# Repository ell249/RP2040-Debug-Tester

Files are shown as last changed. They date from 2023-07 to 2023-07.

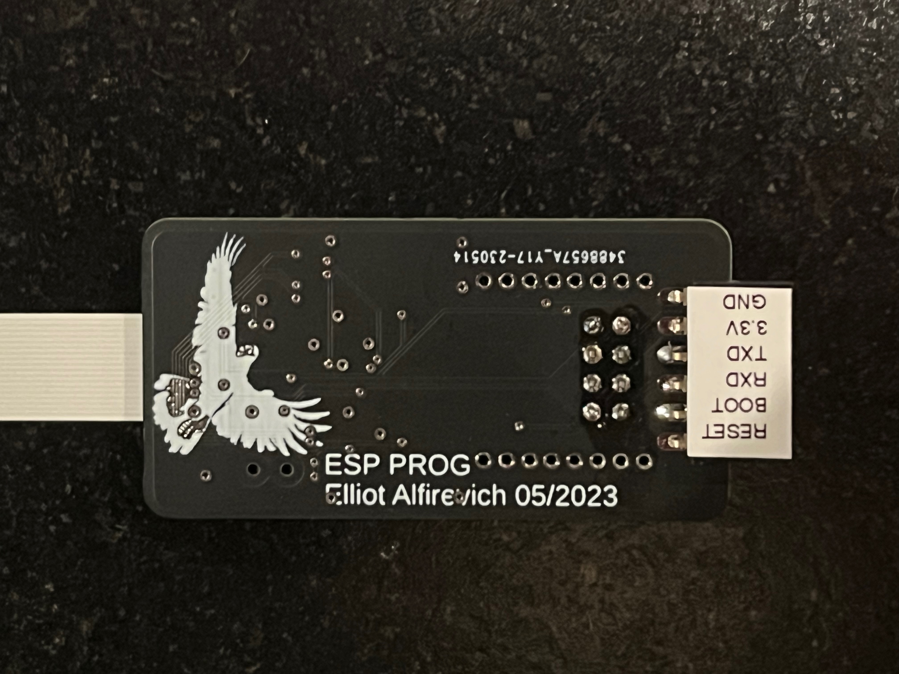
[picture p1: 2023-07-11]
Photos/IMG_8755.jpeg

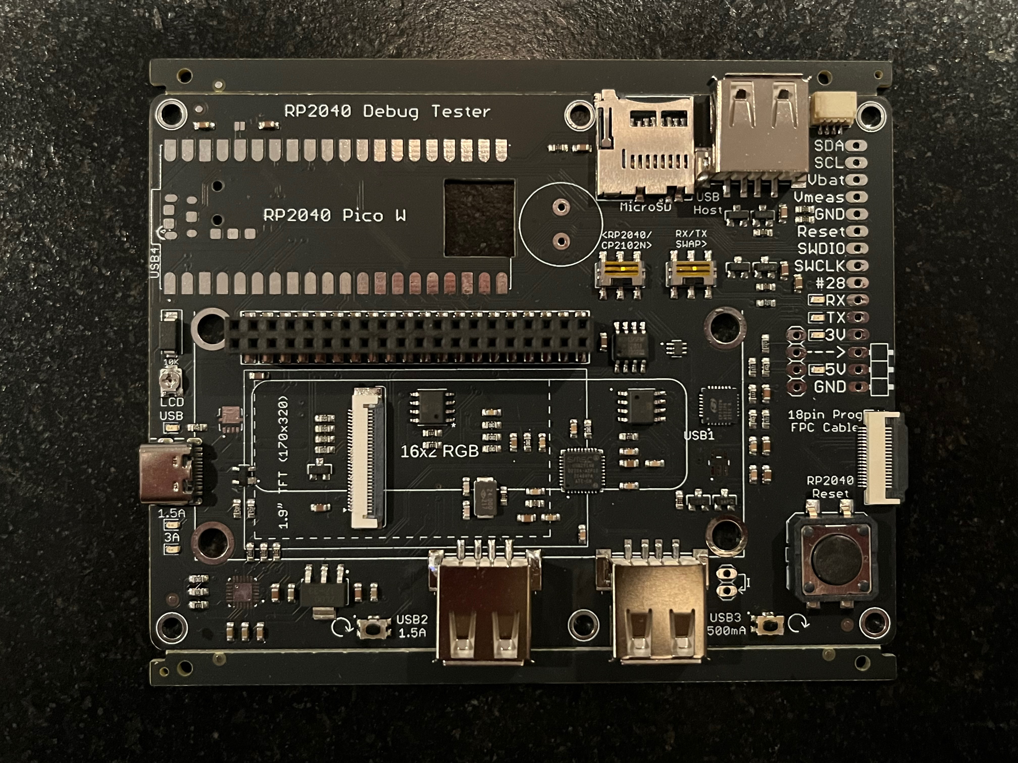
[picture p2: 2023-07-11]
Photos/IMG_8753.jpeg

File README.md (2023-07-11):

## RP2040 Debug Tester
### Licence and design:
-	RP2040 Debug Tester adapted by Elliot Alfirevich http://ell-tech.com/ 
-	Based on Adafruit RP2040 Tester Brains https://github.com/adafruit/RP2040-Based-Tester-Brains-PCB by Adafruit (ladyada & evaherrada) 
-	Licenced under Creative Commons Attribution-ShareAlike 3.0 Unported
-	4-layer impedance controlled circuit board, JLC04161H-7628 to ensure appropriate trace impedance for USB.

### Added features:
1.	USB-Serial converter CP2102N added to snoop serial UART bus, and allow direct serial programming of devices on test using the changeover DPDT switches.
2.	USB Hub with device power reset buttons and USB device current measurement at JP7 using Nordic PPK2 or similar. 
3.	Extra power supply functions added in the FPC 18-pin and external device 0.1in header as JP6.
4.	Additionally JP5 provides connection point for a Nordic PPK2 or similar for measuring load current of external prog-cable devices. “TEST” pin provides opportunity for custom voltages/measured currents. 
5.	Nordic PPK2 can be permanently mounted via the mounting holes and standoffs.

### Notes/changes to Adafruit design:
1.	Dedicated 3.3V regulator provided, in lieu of using the in-built RP2040 buck-boost converter. 
2.	Diode included on 3.3V supply to RP2040 VSYS to prevent back-feeding of ~5V onto the 3.3V bus from plugging in the RP2040 USB port.
3.	USB-C PD controller STUSB4500LQTR ensures enough VBUS current is provided by the host. Previously used 5.1k CC resistor method – but strictly compliant USB hosts would limit supply to 500mA which was not enough.
4.	RTS/DTR logic transistors added for ESP boot/reset to be generated from the CP2102N.
5.	High side switch (Option 1) or separate regulator (Option 2) required to power CP2102N because the CP2102N defaults to pull-up on USB data lines, causing the USB hub to disable the port at start-up (doh!)
6.	USB Hub USB2514B added to enable one cable to the host computer. 
   1.	Port 1 – CP2102N USB-Serial converter
   2.	Port 2 – USB port inc. 1.5A charging
   3.	Port 3 – USB port inc. 500mA power measurement via jumper JP7
   4.	Port 4 – RP2040 via test points.
7.	USB Hub controller strapped to report Port 1 as “non-removable” and enable USB charging support on Port 2.
8.	USB Hub controller requires an external crystal and 1M resistor. Check as newer QFN packages don’t require this resistor.
9.	SD card changed due to part availability. Note new part changes card detect from NO to NC which requires change in Brains library code.
10.	TFT connection not tested. Directly copied from original design.

### Original Adafruit Design
Forked from https://github.com/adafruit/RP2040-Based-Tester-Brains-PCB

This board is what we use internally at Adafruit to program and test boards with microcontrollers on them. 
   * An [RP2040 Pico](https://www.adafruit.com/product/5525) (or perhaps PicoW?) is used to run the test software
   * [Use a 16x2 LCD (ideally RGB backlight)](https://www.adafruit.com/product/398) for display output with color feedback such as green for pass, red for fail. RGB backlight is WS2811-controlled. Don't forget to set the contrast pot on first usage.
   * Serial1 hardware UART has RX/TX pin switch to flip directions
   * 1.9" TFT connector is placed but hasn't been tested or used yet
   * Piezo buzzer can be used for audible feedback alerts
   * STEMMA QT I2C port
   * Big reset button
   * Firmware files can be stored on MicroSD card which is slotted in. 
   * Connect the right hand side, either the 0.1" header or 18-pin EYESPI-like FPC connector to the device-under-test jig which can be different for each product. 
   * [USB Host testing is done with bitbang PIO support in TinyUSB](https://github.com/adafruit/Adafruit_TinyUSB_Arduino), USB 5V power can be turned on / off 
   * Use Philhower RP2040 core for programming
   * The RP2040 brains can perform ESP32 programming, RP2040-via-USB, AVR ICSP/UPDI, or SWD DAP. [See the TestBed library for some examples.](https://github.com/adafruit/Adafruit_TestBed)

### License

Originally designed by Limor Fried/Ladyada for Adafruit Industries. Adafruit invests time and resources providing this open source design, please support Adafruit and open-source hardware by purchasing products from [Adafruit](https://www.adafruit.com)!

Creative Commons Attribution/Share-Alike, all text above must be included in any redistribution. 
See license.txt for additional details.

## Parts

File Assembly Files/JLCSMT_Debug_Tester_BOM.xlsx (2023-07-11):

Comment | Designator | Footprint | JLCPCB Part#
LED_BLUE | 1.5A, 3.3V, 3A, 5V, ATTACH, RX, TX | LEDC1608X55N_FLAT-B | C72038
10uF | C1, C2, C3, C4, C5, C6, C7, C8, C12, C22, C28, C31, C35 | 0603-NO | C194427
1uF | C13, C27, C29, C32, C33, C34 | 0603-NO | C15849
4.7uF | C16, C24, C26 | 0603-NO | C329940
12pF | C18, C21 | 0603-NO | C182482
0.1uF | C9, C10, C11, C14, C15, C17, C19, C20, C23, C25, C30 | 0603-NO | C14663
STEMMA_I2C_QT | CONN1 | JST_SH4 | C160404
B140-13-F | D1 | DIOM5226X290N | C85098
SP0503BAHTG | D2 | SOT143 | C7074
WS2811-SOP8 | IC1 | SO08-SKINNYPADS | C114581
USB4105_REVA | J1 | GCT_USB4105_REVA | C963370
MEM2052-00-195-00-A_REVA | J2 | GCT_MEM2052-00-195-00-A_REVA | C266607
16x2 LCD | JP4 | 2X20_SMT_MALE | C2685092
BSS138 | Q1, Q3, Q5, Q7 | SOT23-WIDE | C2874697
DMG34x5 | Q2, Q4, Q8 | SOT23-WIDE | C96616
10K | R1, R2, R3, R4, R5, R29, R30, R35 | 0603-NO | C309083
1K | R10, R21, R25, R28, R34, R36 | 0603-NO | C103232
27 | R11, R14, R16, R18 | 0603-NO | C881414
100K | R15, R17, R19, R20, R22, R26 | 0603-NO | C103200
1M | R23 | 0603-NO | C217860
12K | R24 | 0603-NO | C217716
20K | R27 | 0603-NO | C163879
22K | R6, R7, R8, R13 | 0603-NO | C705918
47K | R9, R12, R31, R32, R33 | 0603-NO | C912116
DPDT SLIDE | SW1, SW2 | EG1390 | C223854
12mm SMT | SW3 | B3F-40XX-SMT | C2931098
DISP_LCD_ST7789_1.9IN_SS | TFT1 | TFT_1.9IN_170X320_30P_SS | C375905
UMH3NTN | U2 | SOP65P210X100-6N | C123008
CP2102N-A02-GQFN28R | U3 | IC_CP2102N-A02-GQFN28R | C964632
MIC2505-1YM-TRSOIC-8_M_MCH-L | U4 | SOIC-8_M_MCH-L | C627817
MIC2026-1YM | U5 | SOIC127P599X173-8N | C144190
USB2514B-AEZG | U6 | VQFN50P600X600X100-36N | C16251
KMR421GULCLFS | USB2_SW, USB3_SW | SW_KMR421GULCLFS | C99271
10K Trimmer | VR1 | TRIMPOT_BOURNS_TC33X-2 | C719176
NCP1117ST33T3G | VR2 | SOT230P700X170-4 | C444421
USB A | X2, X5, X6 | USB_HOST-SMT | C112455
TESTER_PROGCABLE_FLIP | X3 | FPC_0.5MM_18PIN | C181732
24MHZ 7pf | X4 | NX5032 | C295068

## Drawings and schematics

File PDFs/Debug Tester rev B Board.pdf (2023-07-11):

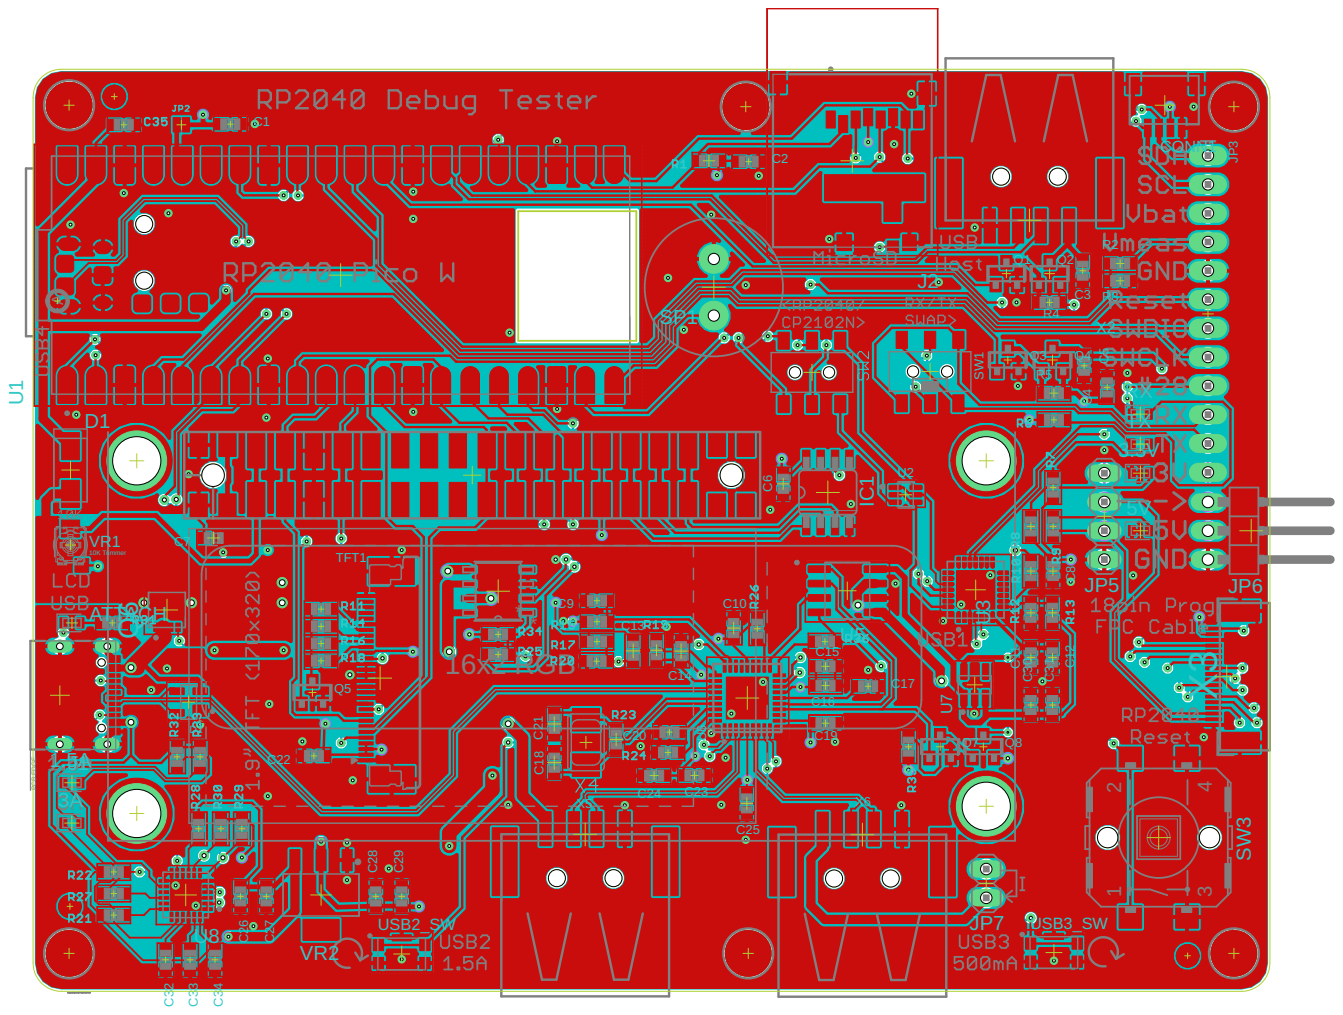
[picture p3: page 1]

X100 3202/ 60, hci verifl At oill Eyb sni ar Br et seT gube D0402PR

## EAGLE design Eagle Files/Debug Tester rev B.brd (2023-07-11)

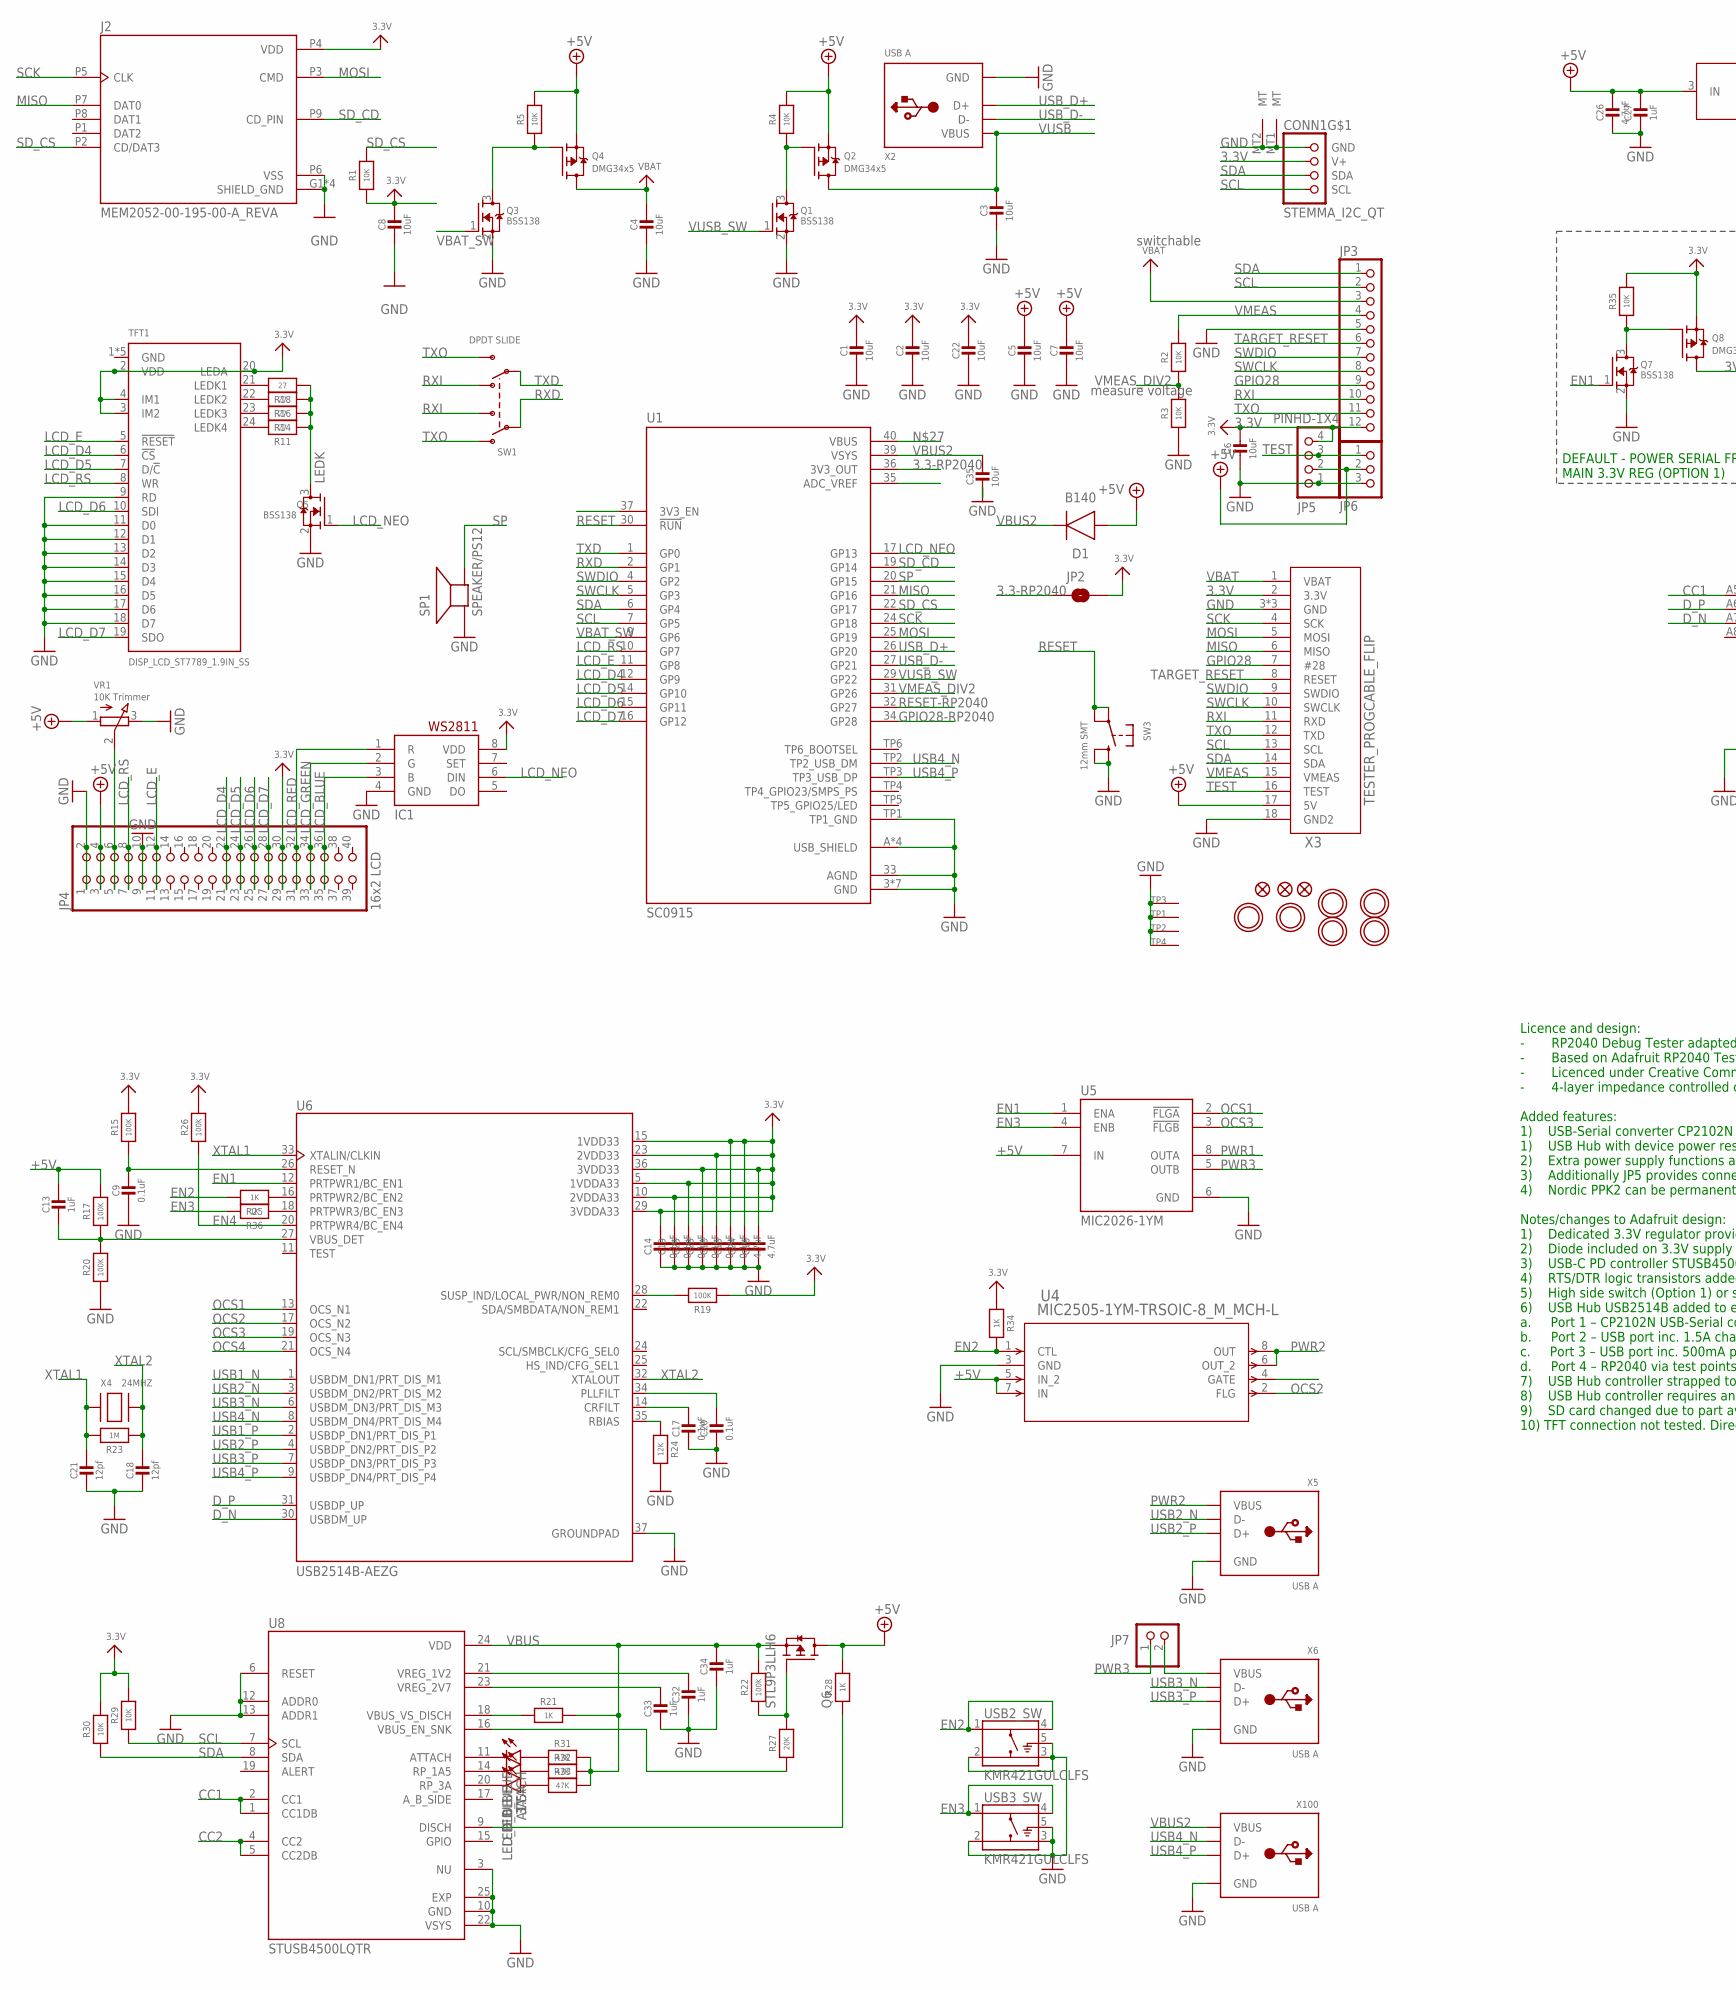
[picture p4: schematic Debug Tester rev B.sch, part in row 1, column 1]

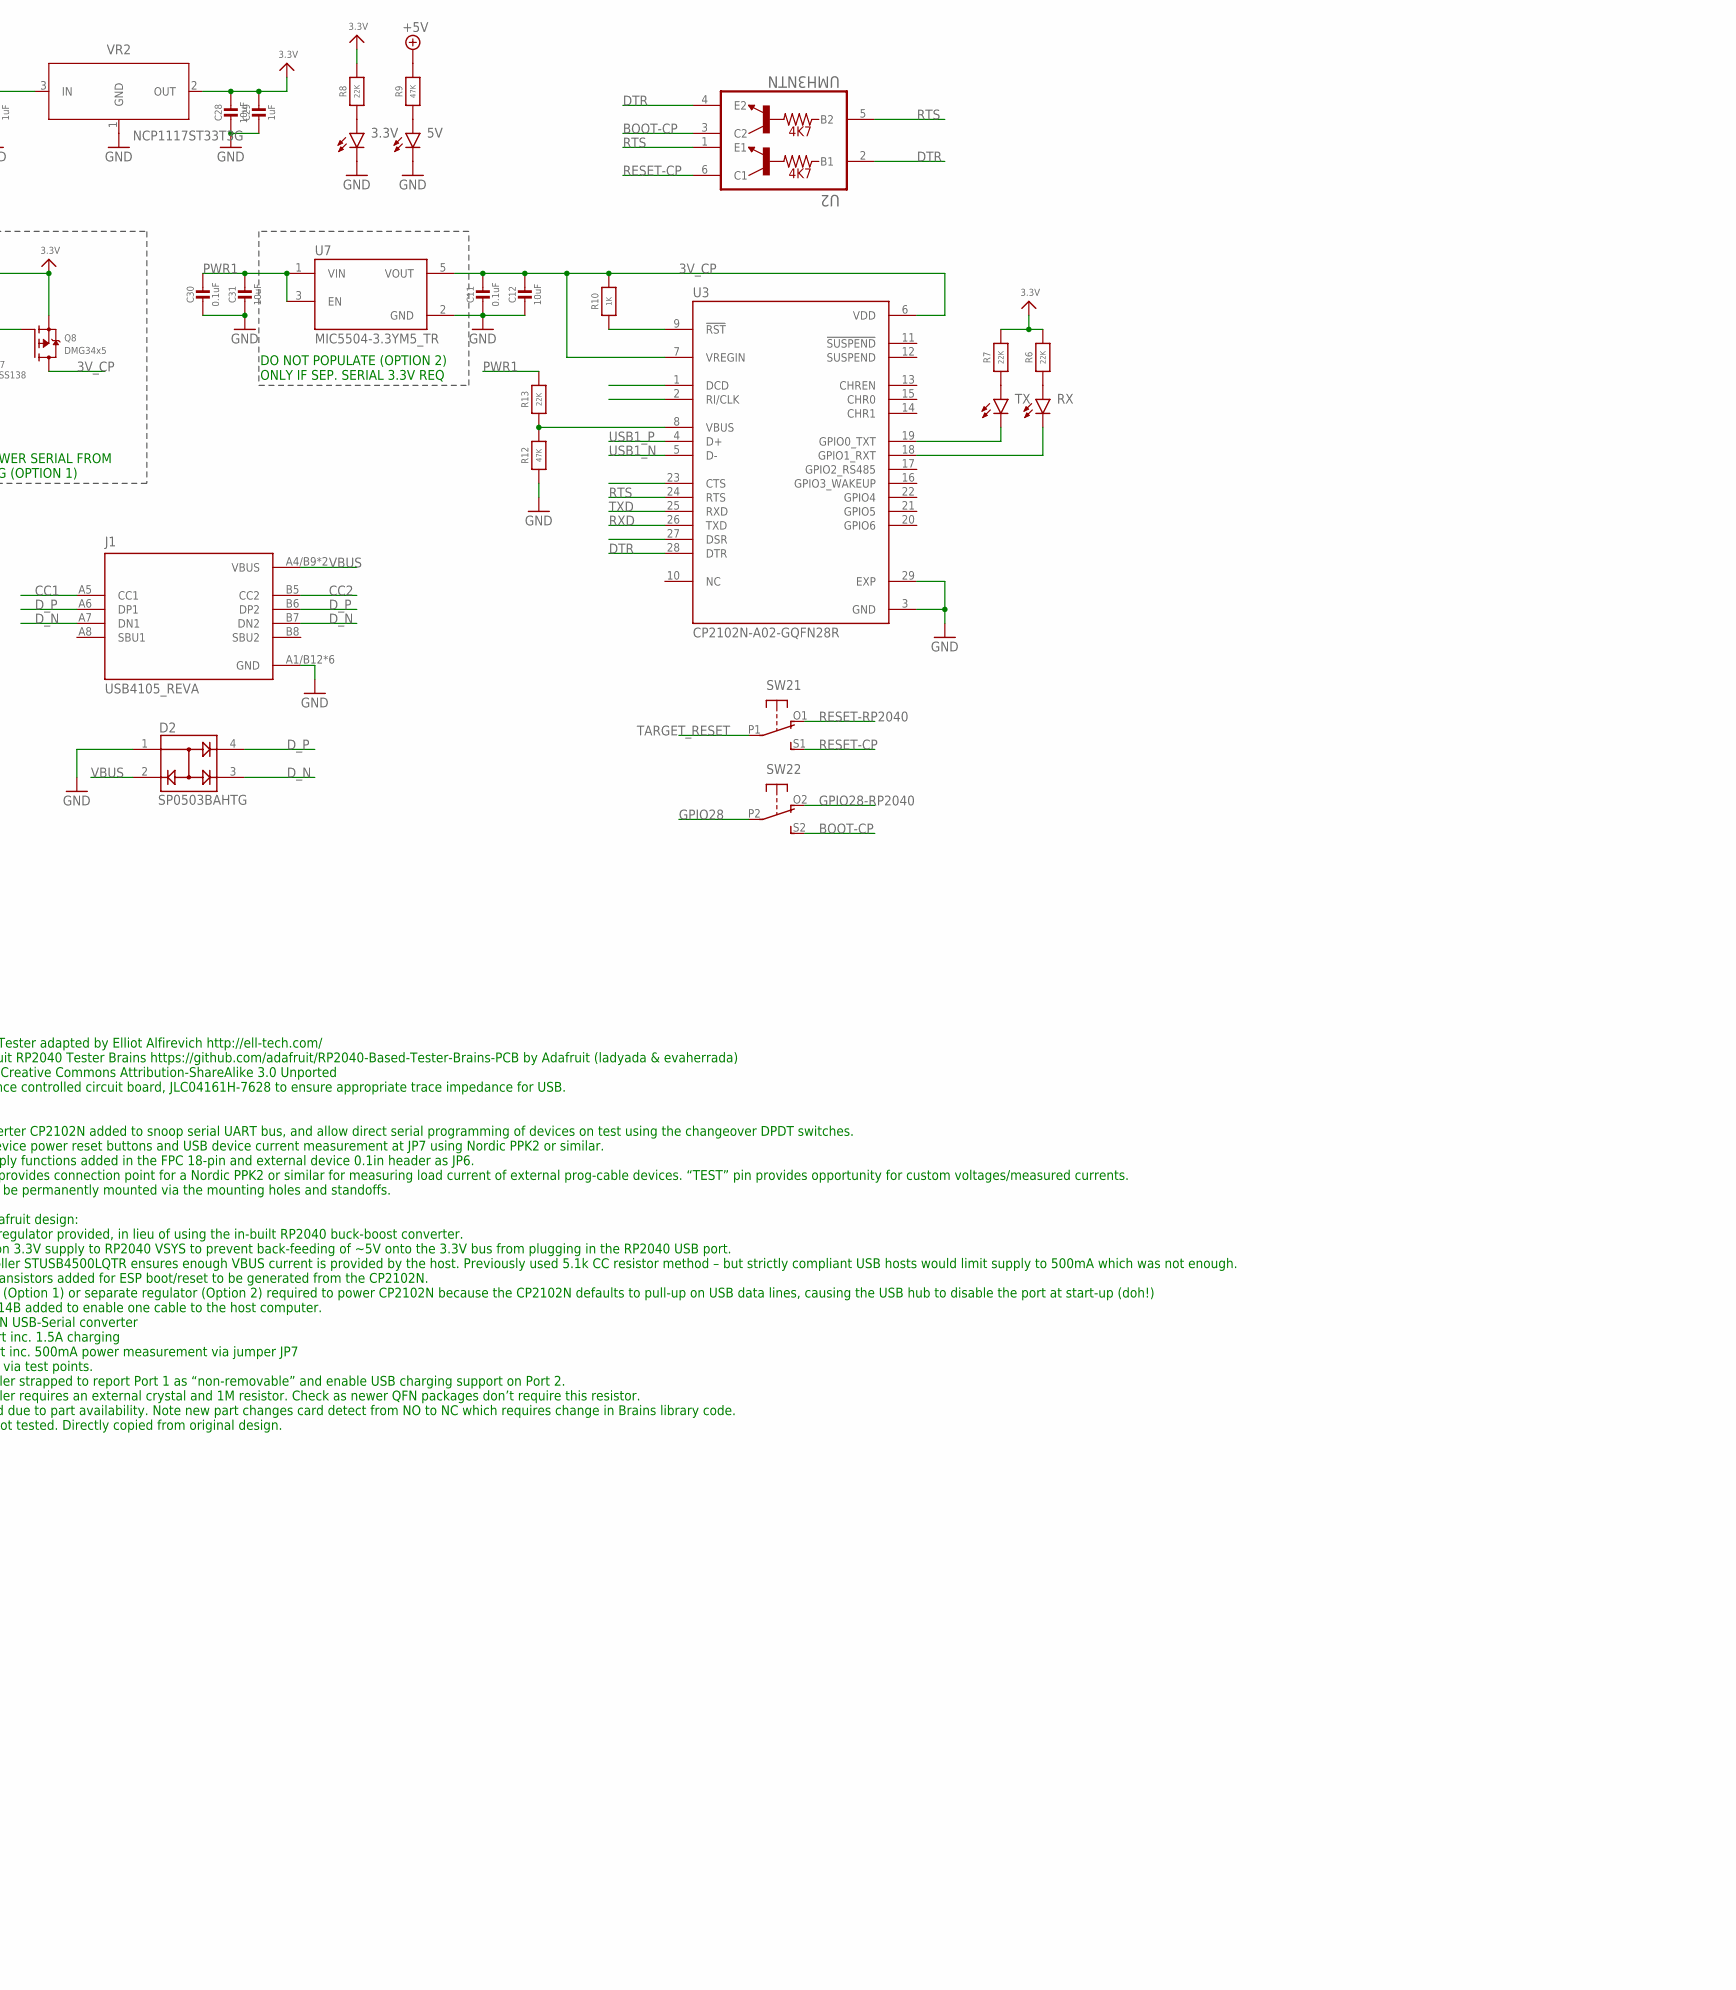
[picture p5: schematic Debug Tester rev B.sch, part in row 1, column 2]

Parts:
1.5A, 3.3V, 3A, 5V: LED_BLUE; LEDC1608X55N_FLAT-B
$$U$1, $$U$2, $$U$3, $$U$5, $$U$6: MOUNTINGHOLE3.0THIN; MOUNTINGHOLE_3.0_PLATEDTHIN
ATTACH: LED_BLUE; LEDC1608X55N_FLAT-B
C1, C2, C3, C4, C5, C6, C7, C8, C12, C22, C28, C31, C35: 10uF; 0603-NO
C9, C10, C11, C14, C15, C17, C19, C20, C23, C25, C30: 0.1uF; 0603-NO
C13, C27, C29, C32, C33, C34: 1uF; 0603-NO
C16, C24, C26: 4.7uF; 0603-NO
C18, C21: 12pf; 0603-NO
CONN1: STEMMA_I2C_QT; JST_SH4
D1: B140; DIOM5226X290N
D2: SP0503BAHTG; SOT143
FID1, FID2, FID3: FIDUCIAL_1MM
IC1: WS2811-SOP8; SO08-SKINNYPADS
J1: USB4105_REVA; GCT_USB4105_REVA
J2: MEM2052-00-195-00-A_REVA; GCT_MEM2052-00-195-00-A_REVA
JP2: JUMPER-SMT_2_NC_PASTE_NO-SILK; SMT-JUMPER_2_NO_NO-SILK
JP3: HEADER-1X12OVAL; 1X12_OVAL
JP4: 16x2 LCD; 2X20_SMT_MALE
JP5: PINHD-1X4; 1X04
JP6: PINHD-1X3/90; 1X03/90
JP7: PINHD-1X2; 1X02
Q1, Q3, Q5, Q7: BSS138; SOT23-WIDE
Q2, Q4, Q8: DMG34x5; SOT23-WIDE
Q6: STL9P3LLH6; TRANS_STL9P3LLH6
R1, R2, R3, R4, R5, R29, R30, R35: 10K; 0603-NO
R6, R7, R8, R13: 22K; 0603-NO
R9, R12, R31, R32, R33: 47K; 0603-NO
R10, R21, R25, R28, R34, R36: 1K; 0603-NO
R11, R14, R16, R18: 27; 0603-NO; LCSC C25190
R15, R17, R19, R20, R22, R26: 100K; 0603-NO
R23: 1M; 0603-NO
R24: 12K; 0603-NO
R27: 20K; 0603-NO
RX: LED_BLUE; LEDC1608X55N_FLAT-B
SP1: SPEAKER/PS12; PS12
SW1: DPDT SLIDE; EG1390; LCSC C318999
SW2: DPDT-EG1390; EG1390
SW3: 12mm SMT; B3F-40XX-SMT
TFT1: DISP_LCD_ST7789_1.9IN_SS; TFT_1.9IN_170X320_30P_SS
TP1, TP2, TP3, TP4: SEWTAP_SMTNUTM3; SMT_NUT_3MM
TX: LED_BLUE; LEDC1608X55N_FLAT-B
U1: SC0915; MODULE_SC0915
U2: UMH3NTN; SOP65P210X100-6N
U3: CP2102N-A02-GQFN28R; IC_CP2102N-A02-GQFN28R
U4: MIC2505-1YM-TRSOIC-8_M_MCH-L; SOIC-8_M_MCH-L
U5: MIC2026-1YM; SOIC127P599X173-8N
U6: USB2514B-AEZG; VQFN50P600X600X100-36N
U7: MIC5504-3.3YM5_TR; SOT95P280X145-5N
U8: STUSB4500LQTR; QFN50P400X400X100-25N
U$7: MOUNTINGHOLE3.0THIN; MOUNTINGHOLE_3.0_PLATEDTHIN
USB2_SW, USB3_SW: KMR421GULCLFS; SW_KMR421GULCLFS
VR1: 10K Trimmer; TRIMPOT_BOURNS_TC33X-2
VR2: NCP1117ST33T3G; SOT230P700X170-4
X2, X5, X6, X100: USB A; USB_HOST-SMT
X3: TESTER_PROGCABLE_FLIP; FPC_0.5MM_18PIN
X4: 24MHZ; NX5032

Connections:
3.3-RP2040: JP2.1, U1.36 (3V3_OUT)
3.3V: C1.1, C2.1, C6.1, C8.1, C10.1, C14.1, C15.1, C16.1, C19.1, C22.1, C23.1, C24.1, C25.1, C28.1, C29.1, CONN1.2 (V+), IC1.8 (VDD), J2.P4 (VDD), JP2.2, JP3.12, JP4.29, JP4.30, JP5.4, Q8.2 (S), R1.1, R6.2, R7.2, R8.2, R15.2, R19.1, R26.2, R29.2, R30.2, R34.1, R35.2, TFT1.2 (VDD), TFT1.3 (IM2), TFT1.4 (IM1), TFT1.20 (LEDA), U6.5 (1VDDA33), U6.10 (2VDDA33), U6.15 (1VDD33), U6.23 (2VDD33), U6.29 (3VDDA33), U6.36 (3VDD33), VR2.2 (OUT), X3.2 (3.3V)
3V_CP: C11.1, C12.1, Q8.3 (D), R10.2, U3.6 (VDD), U3.7 (VREGIN), U7.5 (VOUT)
!VBAT_SW1: Q3.3 (D), Q4.1 (G), R5.1
!VBAT_SW2: Q1.3 (D), Q2.1 (G), R4.1
+5V: C5.1, C7.1, C13.1, C26.1, C27.1, D1.2 (A), JP4.3, JP4.4, JP5.2, JP6.2, Q2.2 (S), Q4.2 (S), Q6.5 (D), Q6.5_1 (D), Q6.5_2 (D), R4.2, R5.2, R9.2, R17.2, R28.2, U4.5 (IN_2), U4.7 (IN), U5.7 (IN), VR1.1 (A), VR2.3 (IN), X3.17 (5V)
BOOT-CP: SW2.S2 (S), U2.3 (C2)
CC1: J1.A5 (CC1), U8.1 (CC1DB), U8.2 (CC1)
CC2: J1.B5 (CC2), U8.4 (CC2), U8.5 (CC2DB)
DTR: U2.2 (B1), U2.4 (E2), U3.28 (DTR)
D_N: D2.3, J1.A7 (DN1), J1.B7 (DN2), U6.30 (USBDM_UP)
D_P: D2.4, J1.A6 (DP1), J1.B6 (DP2), U6.31 (USBDP_UP)
EN1: Q7.1 (G), U5.1 (ENA), U6.12 (PRTPWR1/BC_EN1)
EN2: R25.2, R34.2, U4.1 (CTL), USB2_SW.1, USB2_SW.4
EN3: R36.2, U5.4 (ENB), USB3_SW.1, USB3_SW.4
EN4: R26.1, U6.20 (PRTPWR4/BC_EN4)
GND: 3.3V.C, 5V.C, C1.2, C2.2, C3.2, C4.2, C5.2, C6.2, C7.2, C8.2, C9.2, C10.2, C11.2, C12.2, C14.2, C15.2, C16.2, C17.2, C18.2, C19.2, C20.2, C21.2, C22.2, C23.2, C24.2, C25.2, C26.2, C27.2, C28.2, C29.2, C30.2, C31.2, C32.2, C33.2, C34.2, C35.2, CONN1.1 (GND), CONN1.MT1 (MT), CONN1.MT2 (MT), D2.1, IC1.4 (GND), J1.A1/B12 (GND), J1.B1/A12 (GND), J1.G1 (GND), J1.G2 (GND), J1.G3 (GND), J1.G4 (GND), J2.G1 (SHIELD_GND), J2.G2 (SHIELD_GND), J2.G3 (SHIELD_GND), J2.G4 (SHIELD_GND), J2.P6 (VSS), JP3.5, JP4.1, JP4.2, JP4.9, JP4.10, JP5.1, JP6.3, Q1.2 (S), Q3.2 (S), Q5.2 (S), Q7.2 (S), R3.1, R12.1, R20.1, R24.2, SP1.P$1 (+), SW3.P$3 (S), SW3.P$4 (S1), TFT1.1 (GND), TFT1.9 (RD), TFT1.11 (D0), TFT1.12 (D1), TFT1.13 (D2), TFT1.14 (D3), TFT1.15 (D4), TFT1.16 (D5), TFT1.17 (D6), TFT1.18 (D7), TFT1.25 (GND), TFT1.30 (GND), TFT1.MNT1 (GND), TFT1.MNT2 (GND), TP1.P$1, TP2.P$1, TP3.P$1, TP4.P$1, U1.3 (GND), U1.8 (GND), U1.13 (GND), U1.18 (GND), U1.23 (GND), U1.28 (GND), U1.33 (AGND), U1.38 (GND), U1.A (USB_SHIELD), U1.B (USB_SHIELD), U1.C (USB_SHIELD), U1.D (USB_SHIELD), U1.TP1 (TP1_GND), U3.3 (GND), U3.29 (EXP), U4.3 (GND), U5.6 (GND), U6.37 (GROUNDPAD), U7.2 (GND), U8.3 (NU), U8.6 (RESET), U8.10 (GND), U8.12 (ADDR0), U8.13 (ADDR1), U8.22 (VSYS), U8.25 (EXP), USB2_SW.2, USB2_SW.3, USB2_SW.5 (G), USB3_SW.2, USB3_SW.3, USB3_SW.5 (G), VR1.3 (E), VR2.1 (GND), X2.GND, X3.3 (GND), X3.18 (GND2), X3.SUPPORT1 (GND), X3.SUPPORT2 (GND), X5.GND, X6.GND, X100.GND
GPIO28: JP3.9, SW2.P2, X3.7 (#28)
GPIO28-RP2040: SW2.O2 (O), U1.34 (GP28)
LCD_BLUE: IC1.3 (B), JP4.35, JP4.36
LCD_D4: JP4.21, JP4.22, TFT1.6 (!CS), U1.12 (GP9)
LCD_D5: JP4.23, JP4.24, TFT1.7 (D/!C), U1.14 (GP10)
LCD_D6: JP4.25, JP4.26, TFT1.10 (SDI), U1.15 (GP11)
LCD_D7: JP4.27, JP4.28, TFT1.19 (SDO), U1.16 (GP12)
LCD_E: JP4.11, JP4.12, TFT1.5 (!RESET), U1.11 (GP8)
LCD_GREEN: IC1.2 (G), JP4.33, JP4.34
LCD_NEO: IC1.6 (DIN), Q5.1 (G), U1.17 (GP13)
LCD_RED: IC1.1 (R), JP4.31, JP4.32
LCD_RS: JP4.7, JP4.8, TFT1.8 (WR), U1.10 (GP7)
LEDK: Q5.3 (D), R11.1, R14.1, R16.1, R18.1
MISO: J2.P7 (DAT0), U1.21 (GP16), X3.6 (MISO)
MOSI: J2.P3 (CMD), U1.25 (GP19), X3.5 (MOSI)
unnamed: R25.1, U6.16 (PRTPWR2/BC_EN2)
unnamed: R18.2, TFT1.21 (LEDK1)
unnamed: R16.2, TFT1.22 (LEDK2)
unnamed: R14.2, TFT1.23 (LEDK3)
unnamed: R11.2, TFT1.24 (LEDK4)
unnamed: JP4.5, JP4.6, VR1.2 (S)
unnamed: R10.1, U3.9 (!RST)
unnamed: C13.2, R17.1, R20.2, U6.27 (VBUS_DET)
unnamed: R12.2, R13.1, U3.8 (VBUS)
unnamed: TX.C, U3.19 (GPIO0_TXT)
unnamed: RX.C, U3.18 (GPIO1_RXT)
unnamed: R7.1, TX.A
unnamed: R6.1, RX.A
unnamed: C9.1, R15.1, U6.26 (RESET_N)
unnamed: C17.1, U6.14 (CRFILT)
unnamed: C20.1, U6.34 (PLLFILT)
unnamed: ATTACH.C, U8.11 (ATTACH)
unnamed: C33.1, U8.23 (VREG_2V7)
unnamed: R24.1, U6.35 (RBIAS)
unnamed: R19.2, U6.28 (SUSP_IND/LOCAL_PWR/NON_REM0)
unnamed: C32.1, U8.21 (VREG_1V2)
unnamed: R36.1, U6.18 (PRTPWR3/BC_EN3)
unnamed: 1.5A.C, U8.14 (RP_1A5)
unnamed: R21.1, U8.18 (VBUS_VS_DISCH)
unnamed: Q6.4 (G), R22.1, R27.2
unnamed: 3.3V.A, R8.1
unnamed: 5V.A, R9.1
unnamed: JP7.2, X6.VBUS
unnamed: 3A.C, U8.20 (RP_3A)
unnamed: R28.1, U8.9 (DISCH)
unnamed: R27.1, U8.16 (VBUS_EN_SNK)
unnamed: ATTACH.A, R31.1
unnamed: 1.5A.A, R32.1
unnamed: 3A.A, R33.1
unnamed: Q7.3 (D), Q8.1 (G), R35.1
OCS1: U5.2 (!FLGA), U6.13 (OCS_N1)
OCS2: U4.2 (FLG), U6.17 (OCS_N2)
OCS3: U5.3 (!FLGB), U6.19 (OCS_N3)
OCS4: U6.21 (OCS_N4)
PWR1: C30.1, C31.1, R13.2, U5.8 (OUTA), U7.1 (VIN), U7.3 (EN)
PWR2: U4.6 (OUT_2), U4.8 (OUT), X5.VBUS
PWR3: JP7.1, U5.5 (OUTB)
RESET: SW3.P$1, SW3.P$2 (P1), U1.30 (!RUN)
RESET-CP: SW2.S1 (S), U2.6 (C1)
RESET-RP2040: SW2.O1 (O), U1.32 (GP27)
RTS: U2.1 (E1), U2.5 (B2), U3.24 (RTS)
RXD: SW1.P1, U1.2 (GP1), U3.26 (TXD)
RXI: JP3.10, SW1.O2, SW1.S1, X3.11 (RXD)
SCK: J2.P5 (CLK), U1.24 (GP18), X3.4 (SCK)
SCL: CONN1.4 (SCL), JP3.2, R29.1, U1.7 (GP5), U8.7 (SCL), X3.13 (SCL)
SDA: CONN1.3 (SDA), JP3.1, R30.1, U1.6 (GP4), U8.8 (SDA), X3.14 (SDA)
SD_CD: J2.P9 (CD_PIN), U1.19 (GP14)
SD_CS: J2.P2 (CD/DAT3), R1.2, U1.22 (GP17)
SP: SP1.P$2 (-), U1.20 (GP15)
SWCLK: JP3.8, U1.5 (GP3), X3.10 (SWCLK)
SWDIO: JP3.7, U1.4 (GP2), X3.9 (SWDIO)
TARGET_RESET: JP3.6, SW2.P1, X3.8 (RESET)
TEST: JP5.3, JP6.1, X3.16 (TEST)
TXD: SW1.P2, U1.1 (GP0), U3.25 (RXD)
TXO: JP3.11, SW1.O1, SW1.S2, X3.12 (TXD)
USB1_N: U3.5 (D-), U6.1 (USBDM_DN1/PRT_DIS_M1)
USB1_P: U3.4 (D+), U6.2 (USBDP_DN1/PRT_DIS_P1)
USB2_N: U6.3 (USBDM_DN2/PRT_DIS_M2), X5.D-
USB2_P: U6.4 (USBDP_DN2/PRT_DIS_P2), X5.D+
USB3_N: U6.6 (USBDM_DN3/PRT_DIS_M3), X6.D-
USB3_P: U6.7 (USBDP_DN3/PRT_DIS_P3), X6.D+
USB4_N: U1.TP2 (TP2_USB_DM), U6.8 (USBDM_DN4/PRT_DIS_M4), X100.D-
USB4_P: U1.TP3 (TP3_USB_DP), U6.9 (USBDP_DN4/PRT_DIS_P4), X100.D+
USB_D+: U1.26 (GP20), X2.D+
USB_D-: U1.27 (GP21), X2.D-
VBAT: C4.1, JP3.3, Q4.3 (D), X3.1 (VBAT)
VBAT_SW: Q3.1 (G), U1.9 (GP6)
VBUS: C34.1, D2.2, J1.A4/B9 (VBUS), J1.B4/A9 (VBUS), Q6.1 (S), Q6.2 (S), Q6.3 (S), R21.2, R22.2, R31.2, R32.2, R33.2, U8.24 (VDD)
VBUS2: C35.1, D1.1 (C), U1.39 (VSYS), X100.VBUS
VMEAS: JP3.4, R2.2, X3.15 (VMEAS)
VMEAS_DIV2: R2.1, R3.2, U1.31 (GP26)
VUSB: C3.1, Q2.3 (D), X2.VBUS
VUSB_SW: Q1.1 (G), U1.29 (GP22)
XTAL1: C21.1, R23.2, U6.33 (XTALIN/CLKIN), X4.P$1
XTAL2: C18.1, R23.1, U6.32 (XTALOUT), X4.P$2

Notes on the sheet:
switchable
measure voltage
DO NOT POPULATE (OPTION 2) ONLY IF SEP. SERIAL 3.3V REQ
DEFAULT - POWER SERIAL FROM MAIN 3.3V REG (OPTION 1)
Licence and design: - RP2040 Debug Tester adapted by Elliot Alfirevich http://ell-tech.com/ - Based on Adafruit RP2040 Tester Brains https://github.com/adafruit/RP2040-Based-Tester-Brains-PCB by Adafruit (ladyada & evaherrada) - Licenced under Creative Commons Attribution-ShareAlike 3.0 Unported - 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

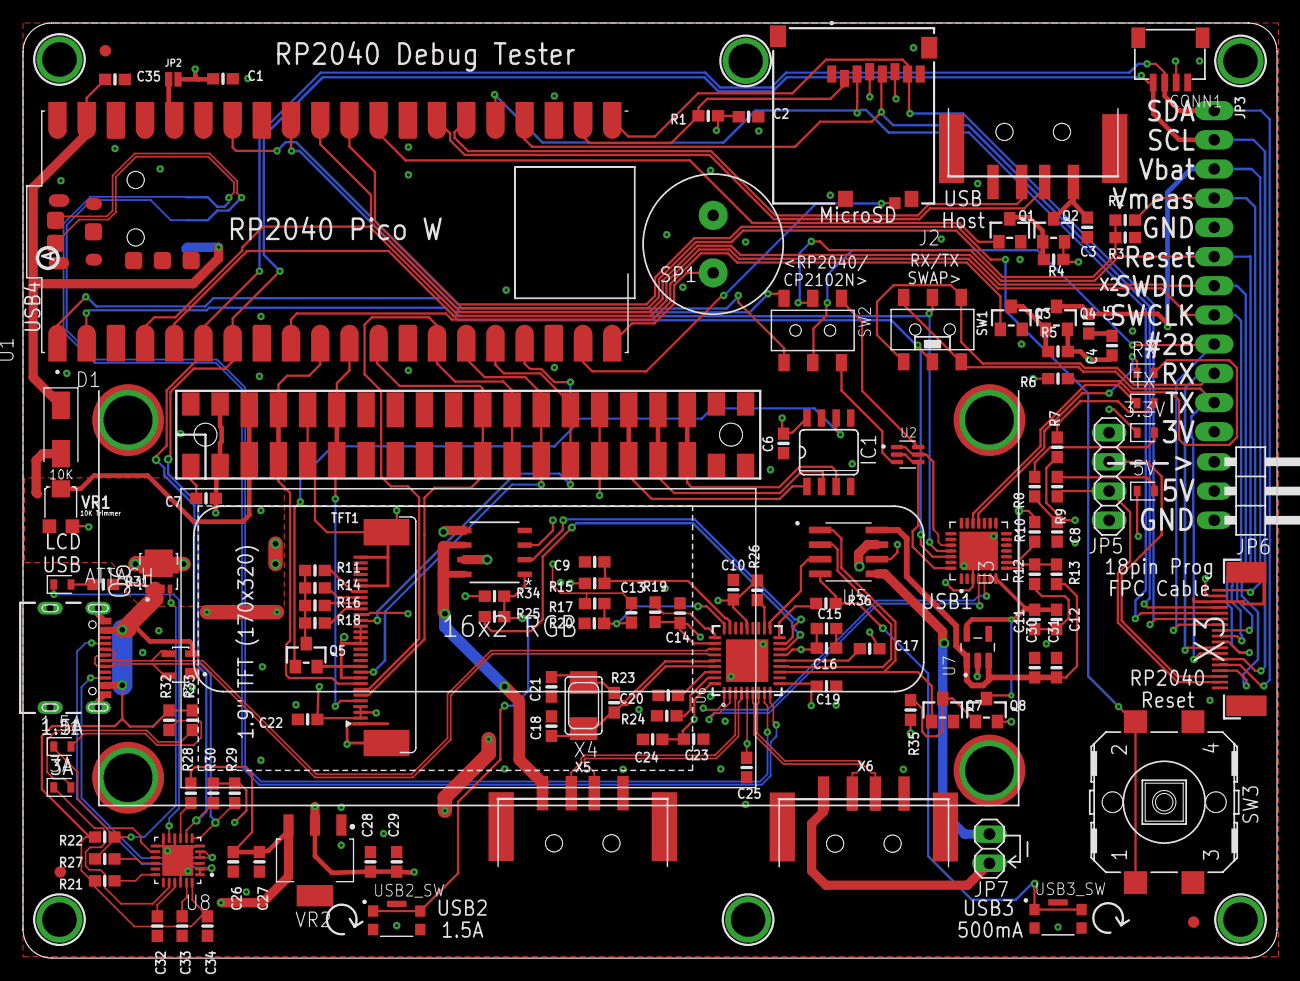
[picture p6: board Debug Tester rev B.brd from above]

Board: 4 copper layers, 109.1 x 81.4 mm, 135 parts (1 on the bottom side), 111 nets.

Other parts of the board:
$$U$4: PCBFEAT-REV-040

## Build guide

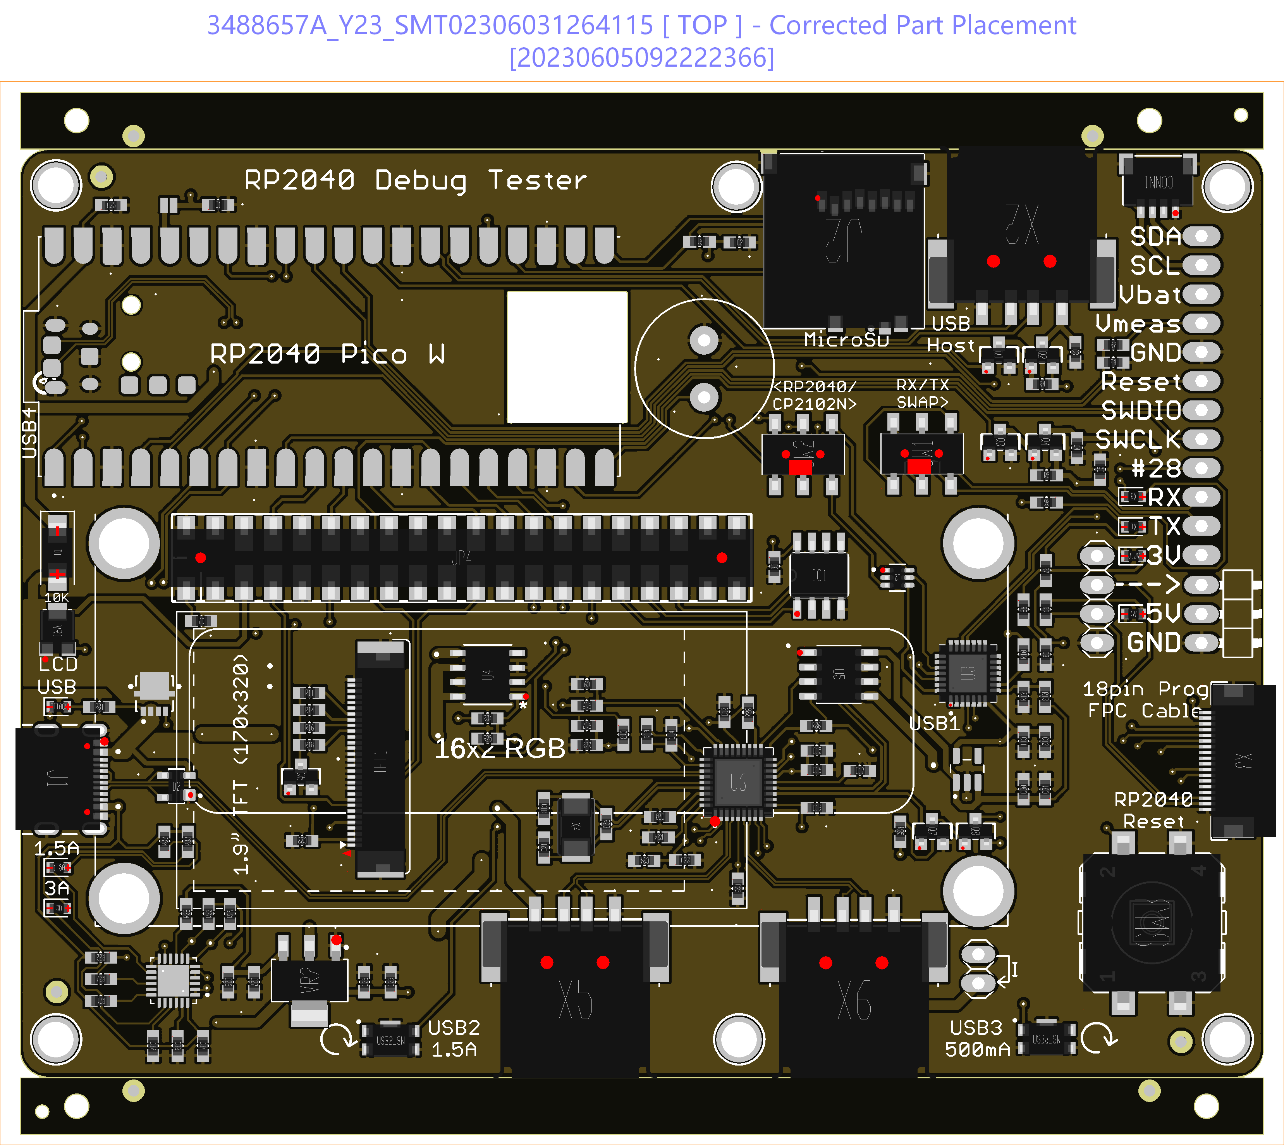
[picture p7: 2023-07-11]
Assembly Files/JLCSMT_Part_Placement_Render.png

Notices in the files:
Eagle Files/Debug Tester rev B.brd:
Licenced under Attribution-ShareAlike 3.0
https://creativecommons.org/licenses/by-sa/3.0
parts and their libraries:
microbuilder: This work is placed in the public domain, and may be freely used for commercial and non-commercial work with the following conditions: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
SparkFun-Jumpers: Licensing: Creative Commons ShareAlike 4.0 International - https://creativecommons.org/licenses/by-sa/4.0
